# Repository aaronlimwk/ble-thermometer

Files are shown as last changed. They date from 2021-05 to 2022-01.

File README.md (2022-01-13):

# BLE Contactless Thermometer 🤒
A BLE contactless thermometer which can distinguish between colds and the flu!

## Front & Back View 🌡️
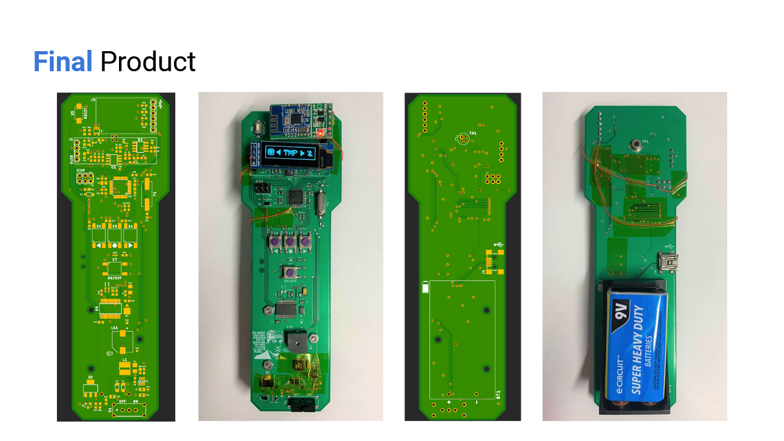
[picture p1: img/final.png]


## Features ⚙️
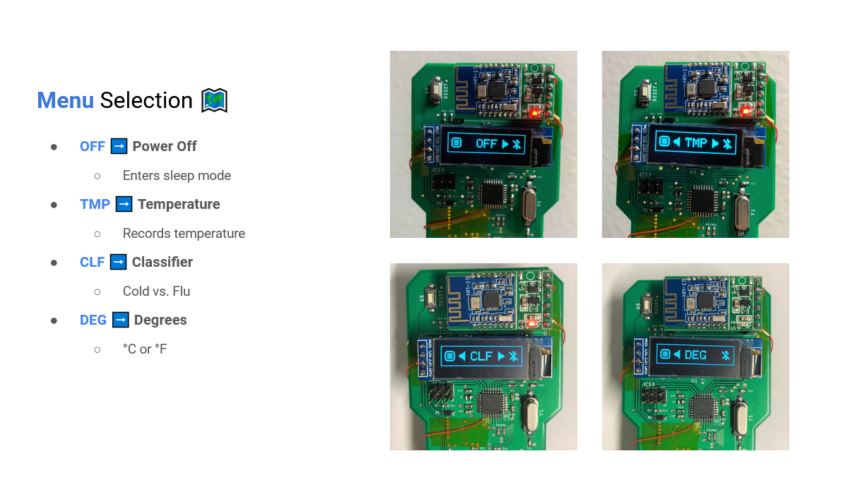
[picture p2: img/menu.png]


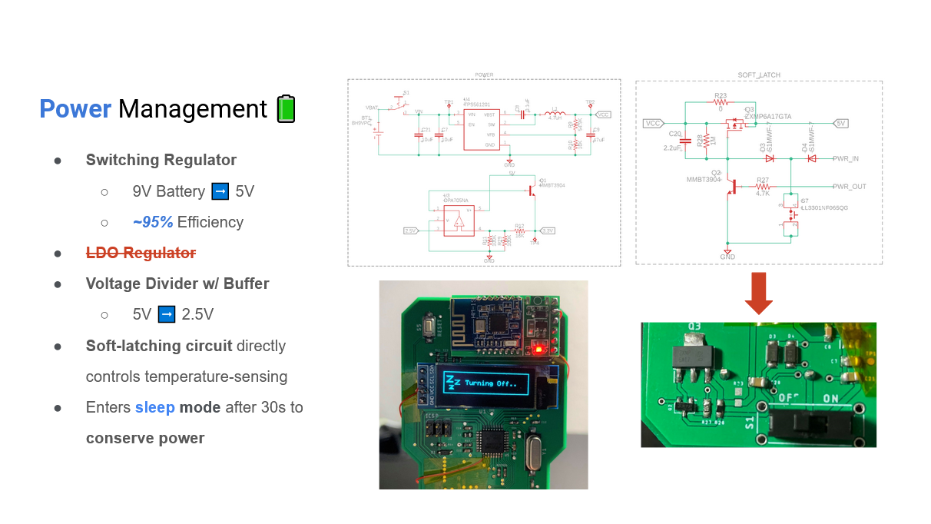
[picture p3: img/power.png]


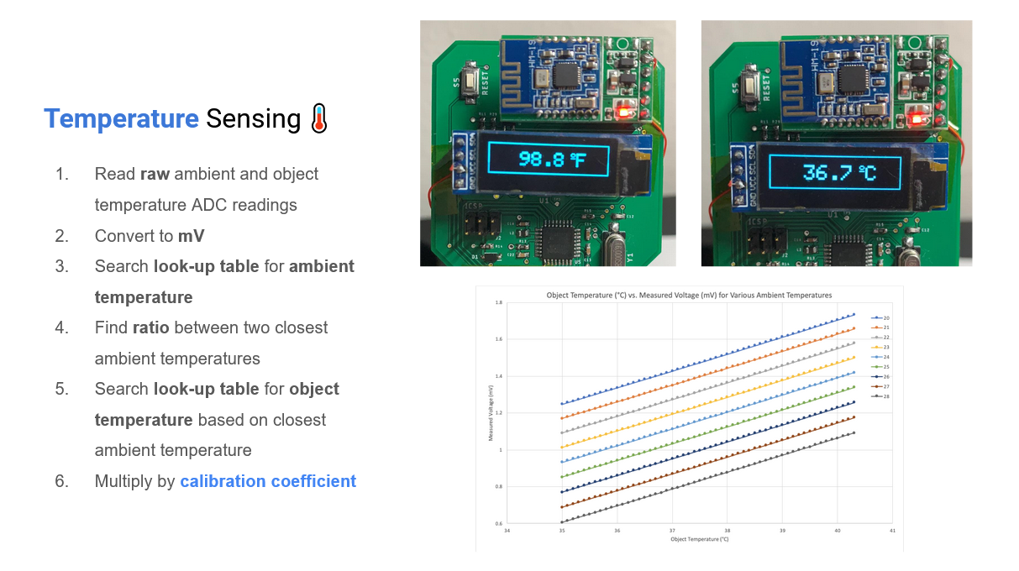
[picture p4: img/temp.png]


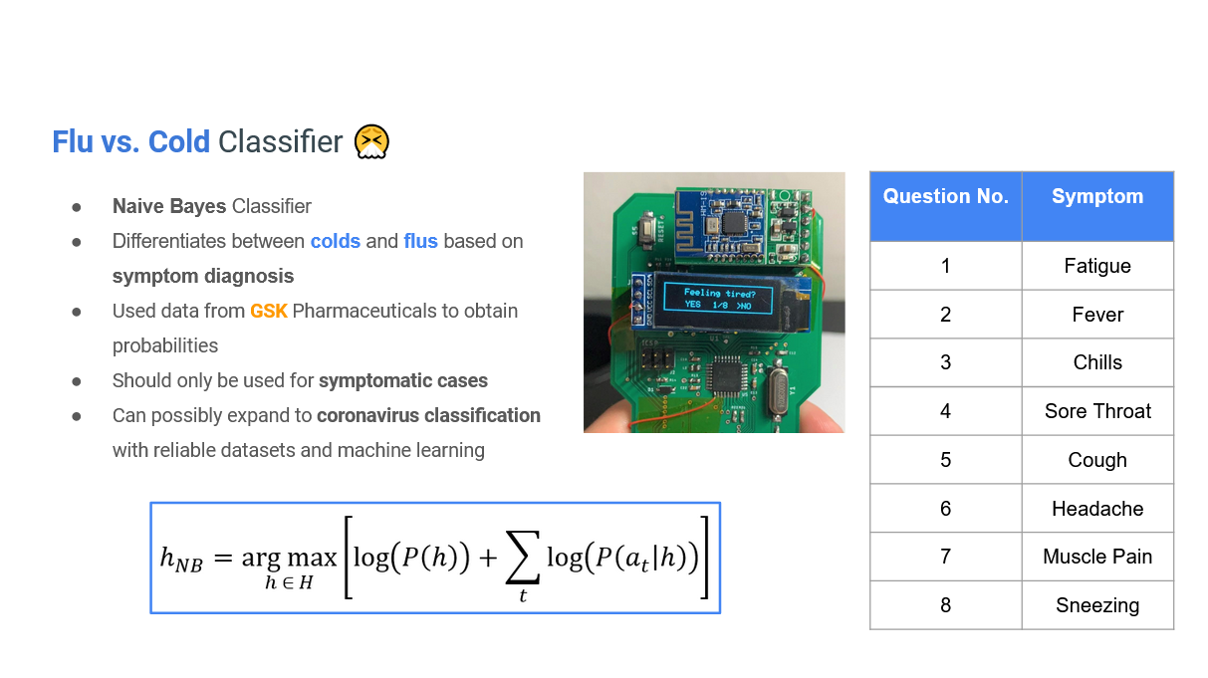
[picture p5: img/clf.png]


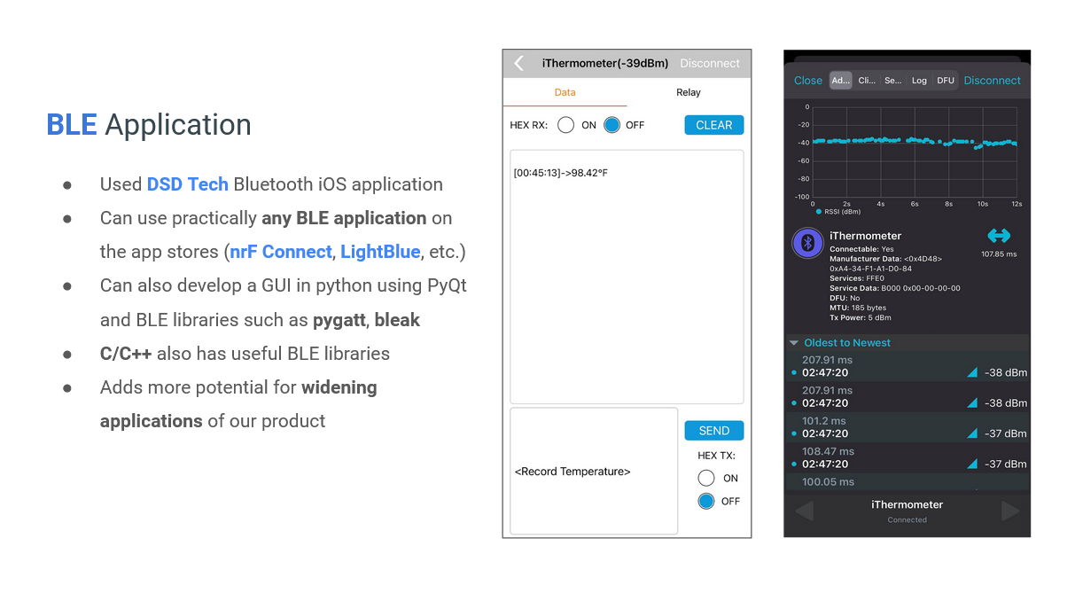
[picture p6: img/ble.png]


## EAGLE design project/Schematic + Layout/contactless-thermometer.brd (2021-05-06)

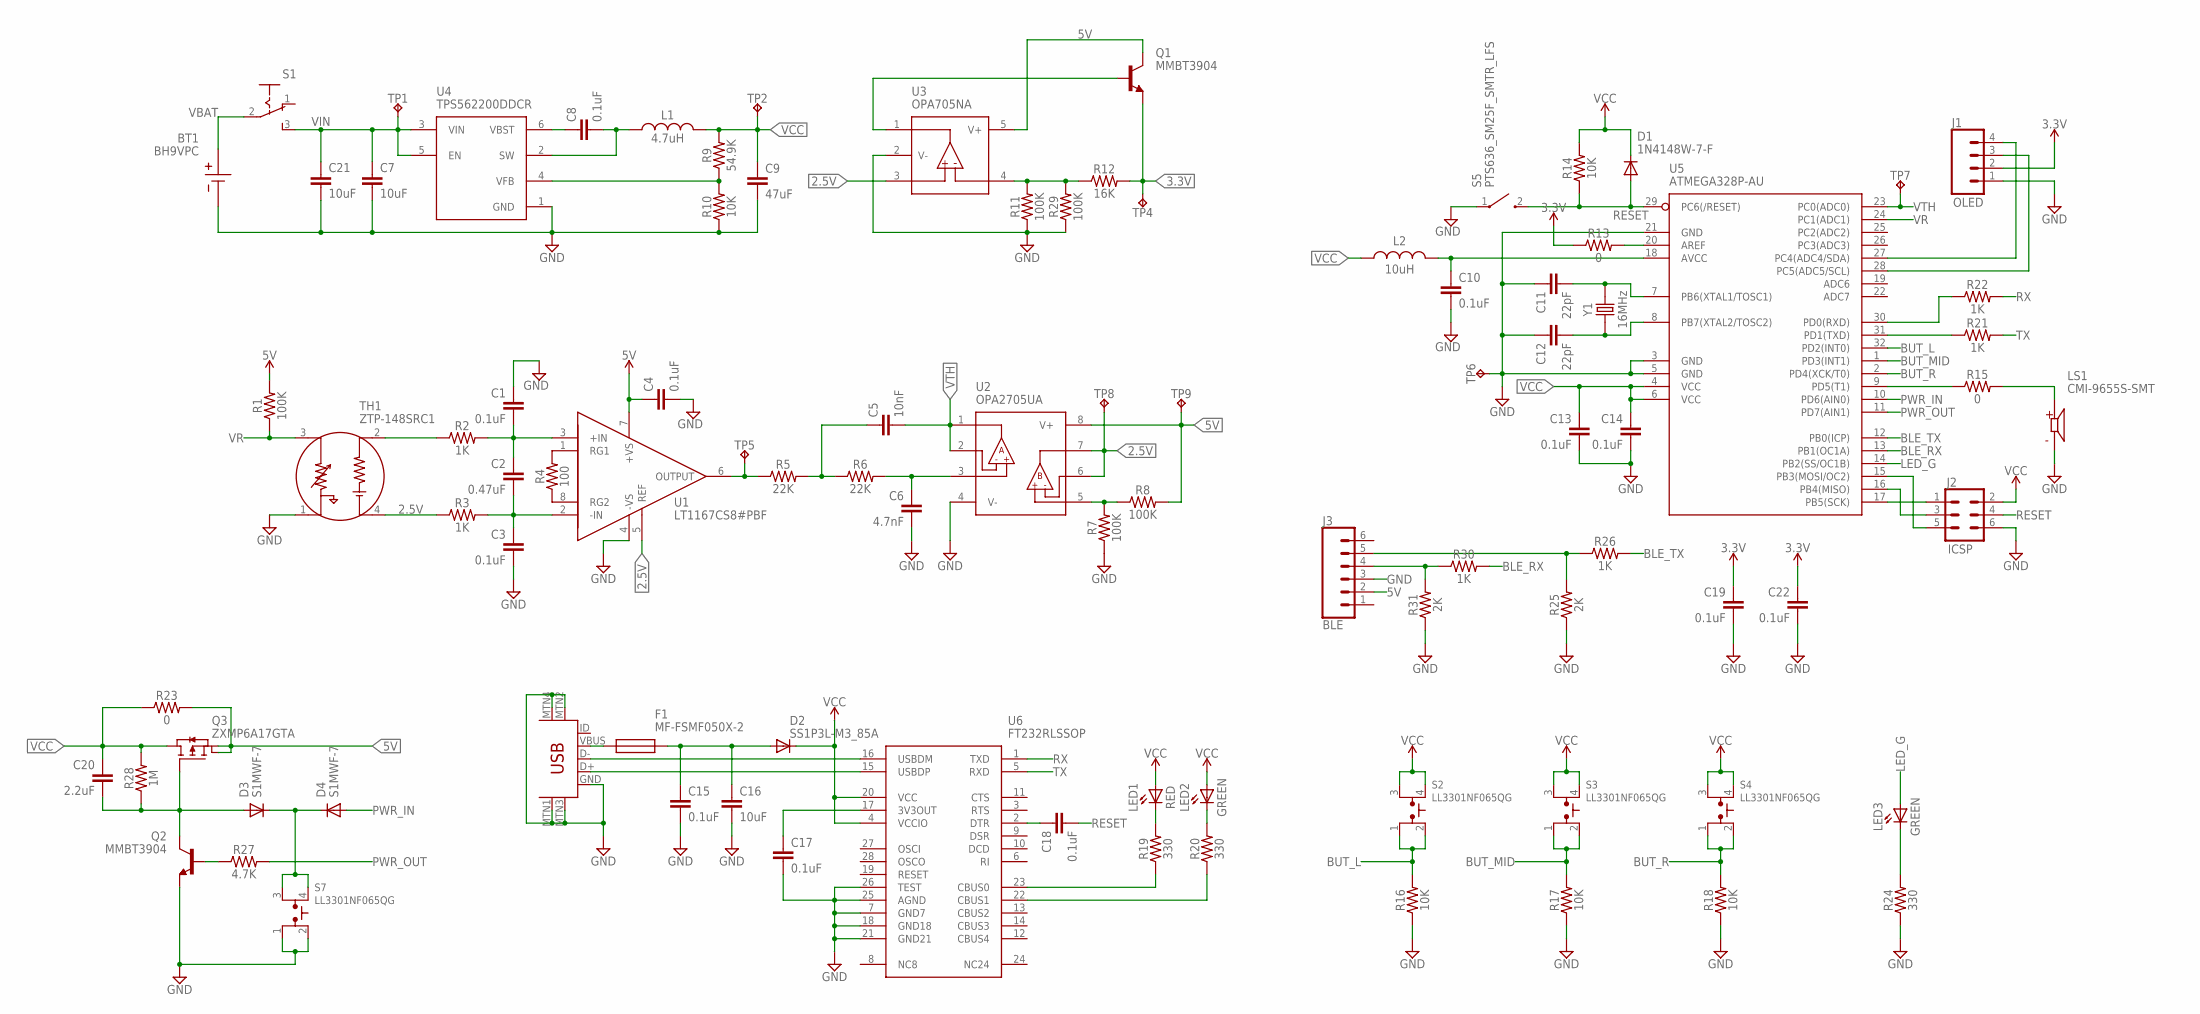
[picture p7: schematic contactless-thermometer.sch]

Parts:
BT1: BH9VPC; BAT_BH9VPC
C1, C3, C4, C8, C10, C13, C14, C15, C17, C18, C19, C22: 0.1uF; 0603
C2: 0.47uF; 0603
C5: 10nF; 0603
C6: 4.7nF; 0603
C7, C21: 10uF; CAPC2012X145N
C9: 47uF; 1206
C11, C12: 22pF; 0603
C16: 10uF; 1206
C20: 2.2uF; CAPC2012X145N
D1: 1N4148W-7-F; SOD3716X145N
D2: SS1P3L-M3_85A; SMP
D3, D4: S1MWF-7; SODFL3518X115N
F1: MF-FSMF050X-2; FUSC1608X100N
J1: OLED; 1X04
J2: ICSP; 2X3
J3: BLE; 1X06
J4: USB-MINIB-5PIN; USB-MINIB
L1: 4.7uH; VLCF5020T4R7N1R71
L2: 10uH; INDC2012X145N
LED1: RED; AA1608CGSK
LED2, LED3: GREEN; AA1608CGSK
LS1: CMI-9655S-SMT; CUI_CMI-9655S-SMT
Q1, Q2: MMBT3904; SOT23_NXP
Q3: ZXMP6A17GTA; SOT230P700X180-4N
R1, R7, R8, R11, R29: 100K; 0603
R2, R3, R21, R22, R26, R30: 1K; 0603
R4: 100; 0603
R5, R6: 22K; 0603
R9: 54.9K; 0603
R10, R14, R16, R17, R18: 10K; 0603
R12: 16K; 0603
R13, R15, R23: 0; 0603
R19, R20, R24: 330; 0603
R25, R31: 2K; 0603
R27: 4.7K; 0603
R28: 1M; 0603
S1: SK12F17G7; SW3_2F17G7_CNK
S2, S3, S4, S7: LL3301NF065QG
S5: PTS636_SM25F_SMTR_LFS; PTS636SM25FSMTRLFS
TH1: ZTP-148SRC1; XDCR_ZTP-148SRC1
TP1, TP2, TP4, TP5, TP6, TP7, TP8, TP9: TPTP10R; TP10R
U1: LT1167CS8#PBF; SOIC127P599X175-8N
U2: OPA2705UA; SOIC127P600X175-8N
U3: OPA705NA; SOT95P280X145-5N
U4: TPS562200DDCR; SOT95P280X110-6N
U5: ATMEGA328P-AU; TQFP32-08
U6: FT232RLSSOP; SOP65P780X200-28N
Y1: 16MHz; XTAL_ECS-240-20-5PX-TR

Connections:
2.5V: R3.1, TH1.4 (THERMOPILE_GND), TP8.TP, U1.5 (REF), U2.6 (-INB), U2.7 (OUTB), U3.3 (+IN)
3.3V: C19.1, C22.1, J1.2, Q1.2, R12.2, R13.1, TP4.TP
5V: C4.1, J3.2, Q1.3, Q3.2 (D1), Q3.4 (D2), R1.2, R8.2, R23.2, TP9.TP, U1.7 (+VS), U2.8 (V+), U3.5 (V+)
AVCC: C10.1, L2.2, U5.18 (AVCC)
BLE_RX: R30.2, U5.13 (PB1(OC1A))
BLE_TX: R26.2, U5.12 (PB0(ICP))
BUT_L: R16.2, S2.1, S2.2, U5.32 (PD2(INT0))
BUT_MID: R17.2, S3.1, S3.2, U5.1 (PD3(INT1))
BUT_R: R18.2, S4.1, S4.2, U5.2 (PD4(XCK/T0))
BUZZ: R15.1, U5.9 (PD5(T1))
DTR: C18.1, U6.2 (DTR)
GND: BT1.-, C1.1, C3.2, C4.2, C6.2, C7.1, C9.2, C10.2, C11.1, C12.1, C13.2, C14.2, C15.2, C16.2, C17.2, C19.2, C21.1, C22.2, J1.1, J2.6, J3.3, J4.GND, J4.MTN1 (MTN2), J4.MTN2 (MTN3), J4.MTN3 (MTN1), J4.MTN4, LS1.N, Q2.2, R7.1, R10.1, R11.1, R16.1, R17.1, R18.1, R24.1, R25.1, R29.1, R31.1, S5.1 (COM), S7.1, S7.2, TH1.1 (THERMISTOR_GND), TP6.TP, U1.4 (-VS), U2.4 (V-), U3.2 (V-), U4.1 (GND), U5.3 (GND), U5.5 (GND), U5.21 (GND), U6.7 (GND7), U6.18 (GND18), U6.21 (GND21), U6.25 (AGND), U6.26 (TEST)
LED_G: LED3.2 (A), U5.14 (PB2(SS/OC1B))
unnamed: C1.2, C2.1, R2.2, U1.3 (+IN)
unnamed: R4.2, U1.1 (RG1)
unnamed: R2.1, TH1.2 (THERMOPILE)
unnamed: C2.2, C3.1, R3.2, U1.2 (-IN)
unnamed: R7.2, R8.1, U2.5 (+INB)
unnamed: R4.1, U1.8 (RG2)
unnamed: R5.1, TP5.TP, U1.6 (OUTPUT)
unnamed: LS1.P, R15.2
unnamed: C5.1, R5.2, R6.1
unnamed: C6.1, R6.2, U2.3 (+INA)
unnamed: R13.2, U5.20 (AREF)
unnamed: J4.D-, U6.16 (USBDM)
unnamed: J4.D+, U6.15 (USBDP)
unnamed: J2.1, U5.17 (PB5(SCK))
unnamed: C8.1, U4.6 (VBST)
unnamed: C11.2, U5.7 (PB6(XTAL1/TOSC1)), Y1.2
unnamed: C12.2, U5.8 (PB7(XTAL2/TOSC2)), Y1.1
unnamed: J2.3, U5.16 (PB4(MISO))
unnamed: C8.2, L1.1, U4.2 (SW)
unnamed: J2.5, U5.15 (PB3(MOSI/OC2))
unnamed: R9.1, R10.2, U4.4 (VFB)
unnamed: R11.2, R12.1, R29.2, U3.4 (-IN)
unnamed: R19.1, U6.23 (CBUS0)
unnamed: J1.4, U5.27 (PC4(ADC4/SDA))
unnamed: LED1.1 (K), R19.2
unnamed: R20.1, U6.22 (CBUS1)
unnamed: J1.3, U5.28 (PC5(ADC5/SCL))
unnamed: LED2.1 (K), R20.2
unnamed: C17.1, U6.17 (3V3OUT)
unnamed: F1.1, J4.VBUS
unnamed: Q1.1, U3.1 (OUT)
unnamed: C15.1, C16.1, D2.1 (A), F1.2
unnamed: R21.1, U5.31 (PD1(TXD))
unnamed: R22.1, U5.30 (PD0(RXD))
unnamed: J3.4, R30.1, R31.2
unnamed: Q2.1, R27.1
unnamed: LED3.1 (K), R24.2
unnamed: J3.5, R25.2, R26.1
unnamed: C20.1, D3.2 (A), Q2.3, Q3.1 (G), R28.1
unnamed: D3.1 (K), D4.1 (K), S7.3, S7.4
PWR_IN: D4.2 (A), U5.10 (PD6(AIN0))
PWR_OUT: R27.2, U5.11 (PD7(AIN1))
RESET: C18.2, D1.2 (A), J2.4, R14.1, S5.2 (NO), U5.29 (PC6(/RESET))
RX: R22.2, U6.1 (TXD)
TX: R21.2, U6.5 (RXD)
VBAT: BT1.+, S1.2
VCC: C9.1, C13.1, C14.1, C20.2, D1.1 (K), D2.2 (K), J2.2, L1.2, L2.1, LED1.2 (A), LED2.2 (A), Q3.3 (S), R9.2, R14.2, R23.1, R28.2, S2.3, S2.4, S3.3, S3.4, S4.3, S4.4, TP2.TP, U5.4 (VCC), U5.6 (VCC), U6.4 (VCCIO), U6.20 (VCC)
VIN: C7.2, C21.2, S1.3, TP1.TP, U4.3 (VIN), U4.5 (EN)
VR: R1.1, TH1.3 (THERMISTOR), U5.24 (PC1(ADC1))
VTH: C5.2, TP7.TP, U2.1 (OUTA), U2.2 (-INA), U5.23 (PC0(ADC0))

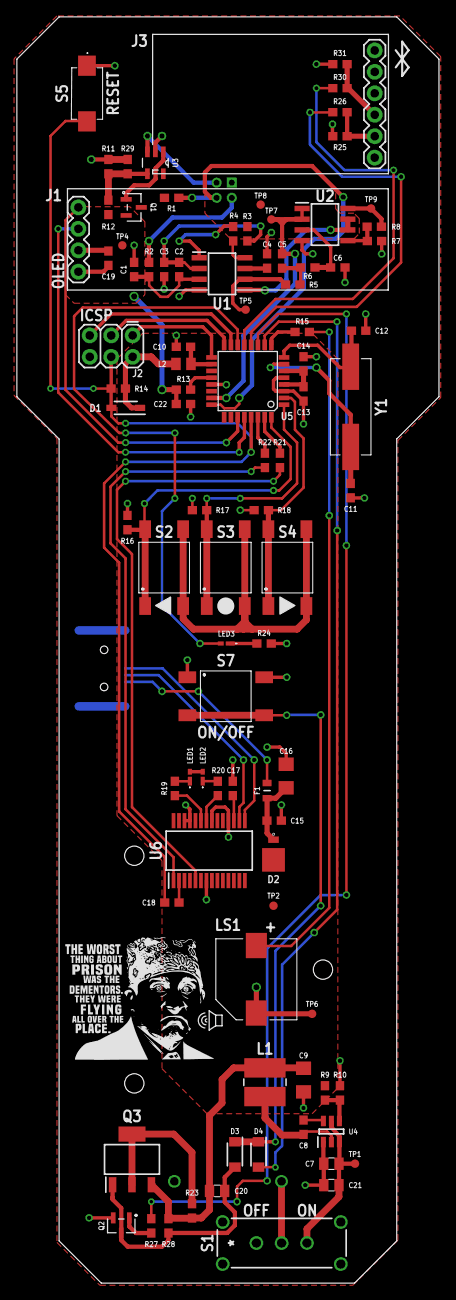
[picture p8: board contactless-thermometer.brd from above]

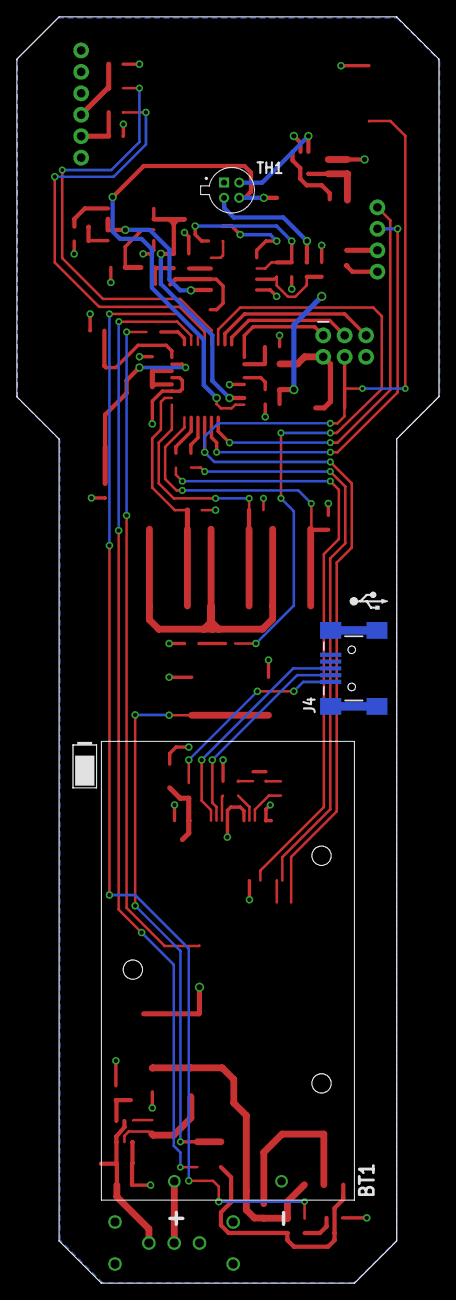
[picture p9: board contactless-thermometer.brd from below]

Board: 2 copper layers, 50.0 x 150.0 mm, 94 parts (3 on the bottom side), 63 nets.

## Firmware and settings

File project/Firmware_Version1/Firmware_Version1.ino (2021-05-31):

#include <SoftwareSerial.h>
#include <OneButton.h>
#include <Wire.h>
#include <Adafruit_SSD1306.h>
#include <avr/pgmspace.h>
#include <RunningMedian.h>

// Baud Rate
#define baud 9600

// Pin Definitions
#define BUT_L             2
#define BUT_MID           3
#define BUT_R             4
#define BUZZ              5
#define PWR_IN            6
#define PWR_OUT           7
#define LED               10
#define VTH               14
#define VR                15
#define BLE_STATE         16

// Bluetooth Message Handler + Setup
char message[20];
bool message_incoming = false;
SoftwareSerial mySerial(9, 8); // RX, TX
int ble_conn_count = 0;
bool ble_connected = false;

// Sleep Sequence Frames
#define SLEEP_FRAMES      4

// OLED Definitions
#define SCREEN_WIDTH      128 // OLED display width, in pixels
#define SCREEN_HEIGHT     32 // OLED display height, in pixels
#define OLED_RESET        -1 // Reset pin # (or -1 if sharing Arduino reset pin)
#define SCREEN_ADDRESS    0x3C ///< See datasheet for Address; 0x3D for 128x64, 0x3C for 128x32
Adafruit_SSD1306 display(SCREEN_WIDTH, SCREEN_HEIGHT, &Wire, OLED_RESET);

// 'Menu Bar Icon', 20x20px
const unsigned char menu_bmp [] PROGMEM = {
  0x00, 0x00, 0x00, 0x00, 0x00, 0x00, 0x07, 0xfe, 0x00, 0x1f, 0xff, 0x80, 0x18, 0x01, 0x80, 0x30,
  0x00, 0xc0, 0x33, 0xfc, 0xc0, 0x33, 0xfc, 0xc0, 0x30, 0x00, 0xc0, 0x33, 0xfc, 0xc0, 0x33, 0xfc,
  0xc0, 0x30, 0x00, 0xc0, 0x33, 0xfc, 0xc0, 0x33, 0xfc, 0xc0, 0x30, 0x00, 0xc0, 0x18, 0x01, 0x80,
  0x1f, 0xff, 0x80, 0x07, 0xfe, 0x00, 0x00, 0x00, 0x00, 0x00, 0x00, 0x00
};

// 'Bluetooth Disabled Icon', 20x20px
const unsigned char ble_off_bmp [] PROGMEM = {
  0x00, 0x00, 0x00, 0x00, 0x00, 0x00, 0x00, 0x60, 0x00, 0x08, 0x70, 0x00, 0x1c, 0x78, 0x00, 0x0e,
  0x7c, 0x00, 0x07, 0x2e, 0x00, 0x03, 0x9c, 0x00, 0x01, 0xc8, 0x00, 0x00, 0xe0, 0x00, 0x00, 0xf0,
  0x00, 0x01, 0xf8, 0x00, 0x03, 0xfc, 0x00, 0x07, 0x6e, 0x00, 0x0e, 0x6f, 0x00, 0x04, 0x7b, 0x80,
  0x00, 0x71, 0x00, 0x00, 0x60, 0x00, 0x00, 0x00, 0x00, 0x00, 0x00, 0x00
};

// 'Bluetooth Enabled Icon', 20x20px
const unsigned char ble_on_bmp [] PROGMEM = {
  0x00, 0x00, 0x00, 0x00, 0x00, 0x00, 0x00, 0x60, 0x00, 0x00, 0x70, 0x00, 0x04, 0x78, 0x00, 0x0e,
  0x7c, 0x00, 0x07, 0x6e, 0x00, 0x03, 0xfc, 0x00, 0x01, 0xf8, 0x00, 0x00, 0xf0, 0x00, 0x00, 0xf0,
  0x00, 0x01, 0xf8, 0x00, 0x03, 0xfc, 0x00, 0x07, 0x6e, 0x00, 0x0e, 0x7c, 0x00, 0x04, 0x78, 0x00,
  0x00, 0x70, 0x00, 0x00, 0x60, 0x00, 0x00, 0x00, 0x00, 0x00, 0x00, 0x00
};

// 'Sleeping Mode Icon', 20x20px
const unsigned char sleep_bmp [] PROGMEM = {
  0xff, 0xc0, 0x00, 0x7f, 0xc0, 0x00, 0x01, 0x80, 0x00, 0x03, 0x00, 0x00, 0x06, 0x00, 0x00, 0x0c,
  0x00, 0x00, 0x18, 0x0f, 0xf0, 0x30, 0x00, 0x60, 0x7f, 0xc0, 0xc0, 0xff, 0xc1, 0x80, 0x00, 0x03,
  0x00, 0x00, 0x06, 0x00, 0x00, 0x0f, 0xf0, 0x00, 0x00, 0x00, 0x0f, 0xe0, 0x00, 0x00, 0xc0, 0x00,
  0x01, 0x80, 0x00, 0x03, 0x00, 0x00, 0x07, 0xc0, 0x00, 0x0f, 0xe0, 0x00
};

const char string_off[] PROGMEM = "OFF";
const char string_tmp[] PROGMEM = "TMP";
const char string_clf[] PROGMEM = "CLF";
const char string_deg[] PROGMEM = "DEG";

const char *const string_table[] PROGMEM = {string_off, string_tmp, string_clf, string_deg};

char buffer[20];

// Classifier Declarations
#define MAX_QUESTION      8

const char question_1[] PROGMEM = "Feeling tired?"; // (24, 6)
const char question_2[] PROGMEM = "Fever?";         // (50, 6)
const char question_3[] PROGMEM = "Chills?";        // (46, 6)
const char question_4[] PROGMEM = "Sore throat?";   // (28, 6)
const char question_5[] PROGMEM = "Coughing?";      // (40, 6)
const char question_6[] PROGMEM = "Headache?";      // (40, 6)
const char question_7[] PROGMEM = "Muscle pain?";   // (28, 6)
const char question_8[] PROGMEM = "Sneezing?";      // (40, 6)

int question_num = 0;

const char *const questions[] PROGMEM = {question_1, question_2, question_3, question_4, question_5, question_6, question_7, question_8};
const int position_x[8] = {24, 50, 47, 29, 40, 40, 29, 40};

#define FLU               0.001

const float flu_table[] PROGMEM = {0.8, 0.9, 0.9, 0.55, 0.9, 0.85, 0.675, 0.25};
float prob_flu = log(FLU);

#define COLD              0.999

const float cold_table[] PROGMEM = {0.225, 0.005, 0.1, 0.5, 0.4, 0.25, 0.1, 0.9};
float prob_cold = log(COLD);

// State Definitions
#define SLEEP_STATE       -1
#define MIN_STATE         0
#define DEFAULT_STATE     1
#define CLF_STATE         2
#define MAX_STATE         3

#define TEMP_REC_STATE    10

#define CLF_NO_STATE      30
#define CLF_YES_STATE     31

#define CELSIUS_STATE     40
#define FAHRENHEIT_STATE  41

#define MAX_TIME          25000
#define SLEEP_TIME        30000

#define SAMPLE_SIZE       40
#define ADC_RES           1024
#define V_REF             5
#define OFFSET            2.5
#define GAIN              1977
#define MV                1000
#define CAL_CONST         0.725
#define NUM_AMBIENT       11
#define MAX_TEMP_SIZE     54

RunningMedian temp_samples = RunningMedian(SAMPLE_SIZE);

double temp_c = 0;
double temp_f = 0;

bool deg_celsius = true;

int state = DEFAULT_STATE;
unsigned long last_millis = 0;
unsigned long last_interrupt_millis = 0;

// Button Setup
OneButton but_left = OneButton(BUT_L, false, false);
OneButton but_middle = OneButton(BUT_MID, false, false);
OneButton but_right = OneButton(BUT_R, false, false);

// Power Button
bool power_on = false;
OneButton pwr_in = OneButton(PWR_IN, true, true);

// Temperature Chart
const float temp_chart[11][54] PROGMEM = {
  // 20 degrees Celsius
  { 1.247, 1.256, 1.265, 1.274, 1.283, 1.292, 1.301, 1.310, 1.319, 1.328, 1.337, 1.346, 1.355, 1.364, 1.373, 1.382, 1.391, 1.400, 1.409, 1.418, 1.427, 1.437, 1.446, 1.455, 1.464, 1.473, 1.482,
    1.491, 1.501, 1.510, 1.519, 1.528, 1.537, 1.547, 1.556, 1.565, 1.574, 1.584, 1.593, 1.602, 1.612, 1.621, 1.630, 1.639, 1.649, 1.658, 1.668, 1.677, 1.686, 1.696, 1.705, 1.714, 1.724, 1.733
  },
  // 21 degrees Celsius
  { 1.169, 1.178, 1.187, 1.196, 1.205, 1.214, 1.223, 1.232, 1.241, 1.250, 1.259, 1.268, 1.277, 1.286, 1.295, 1.305, 1.314, 1.323, 1.332, 1.341, 1.350, 1.359, 1.368, 1.377, 1.387, 1.396, 1.405,
    1.414, 1.423, 1.432, 1.442, 1.451, 1.460, 1.469, 1.479, 1.488, 1.497, 1.506, 1.516, 1.525, 1.534, 1.543, 1.553, 1.562, 1.571, 1.581, 1.590, 1.599, 1.609, 1.618, 1.628, 1.637, 1.646, 1.656
  },
  // 22 degrees Celsius
  { 1.091, 1.100, 1.109, 1.118, 1.127, 1.136, 1.145, 1.154, 1.163, 1.172, 1.181, 1.190, 1.199, 1.208, 1.217, 1.226, 1.235, 1.245, 1.254, 1.263, 1.272, 1.281, 1.290, 1.299, 1.308, 1.318, 1.327,
    1.336, 1.345, 1.354, 1.363, 1.373, 1.382, 1.391, 1.400, 1.410, 1.419, 1.428, 1.437, 1.447, 1.456, 1.465, 1.475, 1.484, 1.493, 1.503, 1.512, 1.521, 1.531, 1.540, 1.549, 1.559, 1.568, 1.578
  },
  // 23 degrees Celsius
  { 1.012, 1.021, 1.030, 1.039, 1.048, 1.057, 1.066, 1.075, 1.084, 1.093, 1.102, 1.111, 1.120, 1.129, 1.138, 1.147, 1.156, 1.166, 1.175, 1.184, 1.193, 1.202, 1.211, 1.220, 1.229, 1.239, 1.248,
    1.257, 1.266, 1.275, 1.284, 1.294, 1.303, 1.312, 1.321, 1.331, 1.340, 1.349, 1.358, 1.368, 1.377, 1.386, 1.396, 1.405, 1.414, 1.424, 1.433, 1.442, 1.452, 1.461, 1.470, 1.480, 1.489, 1.499
  },
  // 24 degrees Celsius
  { 0.932, 0.941, 0.950, 0.959, 0.968, 0.977, 0.986, 0.995, 1.004, 1.013, 1.022, 1.031, 1.040, 1.049, 1.058, 1.068, 1.077, 1.086, 1.095, 1.104, 1.113, 1.122, 1.131, 1.140, 1.150, 1.159, 1.168,
    1.177, 1.186, 1.195, 1.205, 1.214, 1.223, 1.232, 1.242, 1.251, 1.260, 1.269, 1.279, 1.288, 1.297, 1.306, 1.316, 1.325, 1.334, 1.344, 1.353, 1.362, 1.372, 1.381, 1.391, 1.400, 1.409, 1.419
  },
  // 25 degrees Celsius
  { 0.852, 0.861, 0.870, 0.879, 0.888, 0.897, 0.906, 0.915, 0.924, 0.933, 0.942, 0.951, 0.960, 0.969, 0.978, 0.987, 0.996, 1.005, 1.014, 1.023, 1.032, 1.042, 1.051, 1.060, 1.069, 1.078, 1.087,
    1.096, 1.106, 1.115, 1.124, 1.133, 1.142, 1.152, 1.161, 1.170, 1.179, 1.189, 1.198, 1.207, 1.217, 1.226, 1.235, 1.245, 1.254, 1.263, 1.273, 1.282, 1.291, 1.301, 1.310, 1.319, 1.329, 1.338
  },
  // 26 degrees Celsius
  { 0.770, 0.779, 0.788, 0.797, 0.806, 0.815, 0.824, 0.833, 0.842, 0.851, 0.860, 0.869, 0.878, 0.887, 0.896, 0.906, 0.915, 0.924, 0.933, 0.942, 0.951, 0.960, 0.969, 0.978, 0.988, 0.997, 1.006,
    1.015, 1.024, 1.033, 1.043, 1.052, 1.061, 1.070, 1.080, 1.089, 1.098, 1.107, 1.117, 1.126, 1.135, 1.144, 1.154, 1.163, 1.172, 1.182, 1.191, 1.200, 1.210, 1.219, 1.229, 1.238, 1.247, 1.257
  },
  // 27 degrees Celsius
  { 0.688, 0.697, 0.706, 0.715, 0.724, 0.733, 0.742, 0.751, 0.760, 0.769, 0.778, 0.787, 0.796, 0.805, 0.814, 0.823, 0.832, 0.841, 0.851, 0.860, 0.869, 0.878, 0.887, 0.896, 0.905, 0.914, 0.924,
    0.933, 0.942, 0.951, 0.960, 0.970, 0.979, 0.988, 0.997, 1.007, 1.016, 1.025, 1.034, 1.044, 1.053, 1.062, 1.072, 1.081, 1.090, 1.100, 1.109, 1.118, 1.128, 1.137, 1.147, 1.156, 1.165, 1.175
  },
  // 28 degrees Celsius
  { 0.605, 0.614, 0.623, 0.632, 0.641, 0.650, 0.659, 0.668, 0.677, 0.686, 0.695, 0.704, 0.713, 0.722, 0.731, 0.740, 0.749, 0.758, 0.767, 0.777, 0.786, 0.795, 0.804, 0.813, 0.822, 0.831, 0.841,
    0.850, 0.859, 0.868, 0.877, 0.887, 0.896, 0.905, 0.914, 0.923, 0.933, 0.942, 0.951, 0.961, 0.970, 0.979, 0.988, 0.998, 1.007, 1.016, 1.026, 1.035, 1.045, 1.054, 1.063, 1.073, 1.082, 1.091
  },
  // 29 degrees Celsius
  { 0.521, 0.530, 0.539, 0.548, 0.557, 0.566, 0.575, 0.584, 0.593, 0.602, 0.611, 0.620, 0.629, 0.638, 0.647, 0.656, 0.665, 0.674, 0.684, 0.693, 0.702, 0.711, 0.720, 0.729, 0.738, 0.748, 0.757,
    0.766, 0.775, 0.784, 0.793, 0.803, 0.812, 0.821, 0.830, 0.840, 0.849, 0.858, 0.867, 0.877, 0.886, 0.895, 0.905, 0.914, 0.923, 0.933, 0.942, 0.951, 0.961, 0.970, 0.979, 0.989, 0.998, 1.008
  },
  // 30 degrees Celsius
  { 0.436, 0.445, 0.454, 0.463, 0.472, 0.481, 0.490, 0.499, 0.508, 0.517, 0.526, 0.535, 0.544, 0.553, 0.563, 0.572, 0.581, 0.590, 0.599, 0.608, 0.617, 0.626, 0.635, 0.644, 0.654, 0.663, 0.672,
    0.681, 0.690, 0.699, 0.709, 0.718, 0.727, 0.736, 0.746, 0.755, 0.764, 0.773, 0.783, 0.792, 0.801, 0.811, 0.820, 0.829, 0.838, 0.848, 0.857, 0.867, 0.876, 0.885, 0.895, 0.904, 0.913, 0.923
  }
};

// Ambient Temperature Chart
const float ambient_chart[11] PROGMEM = {2.78, 2.72, 2.67, 2.61, 2.55, 2.5, 2.45, 2.39, 2.34, 2.28, 2.23};

void setup() {
  // Pin Setup
  pinMode(BLE_STATE, INPUT);
  pinMode(VTH, INPUT);
  pinMode(PWR_OUT, OUTPUT);
  pinMode(LED, OUTPUT);
  pinMode(BUZZ, OUTPUT);
  //Turn off LED
  digitalWrite(LED, LOW);

  // Begin Serial Communication for HM-11 and Board
  mySerial.begin(baud);

  // Button Click - Function Link
  but_left.attachClick(leftClick);
  but_left.attachLongPressStart(holdLeft);

  but_right.attachClick(rightClick);

  but_middle.attachClick(middleClick);
  but_middle.attachLongPressStart(holdClick);

  pwr_in.attachClick(powerON);
  pwr_in.attachLongPressStart(holdRecord);

  // OLED Setup
  // SSD1306_SWITCHCAPVCC => Generate display voltage from 3.3V internally
  if (!display.begin(SSD1306_SWITCHCAPVCC, SCREEN_ADDRESS)) {
    // Serial.println(F("SSD1306 allocation failed"));
    for (;;); // Don't proceed, loop forever!
  }

  // Show initial display buffer contents on the screen.
  // The library initializes this with an Adafruit splash screen.
  display.display();
  delay(1750); // Pause for 2 seconds

  // Clear the buffer
  display.clearDisplay();

  // Default Font
  display.setTextSize(2);
  display.setTextColor(SSD1306_WHITE);
  display.cp437(true);

  // BLE Setup
  at("AT+NAMEiThermometer");
  at("AT+ROLE0"); // Set peripheral mode
  at("AT+IMME0"); // Work immediately
  at("AT+RESET"); // Actually more a restart than a reset => Needed after ROLE
  delay(1000);
}

void loop() {
  but_left.tick();
  but_right.tick();
  but_middle.tick();
  pwr_in.tick();

  display.clearDisplay();
  display.setTextSize(2);

  if (ble_connected == false) {
    if (digitalRead(BLE_STATE) == 1) {
      if (ble_conn_count == 20) {
        ble_connected = true;
        BLESequence();
        ble_conn_count = 0;
      } else {
        ble_conn_count++;
      }
    } else {
      ble_conn_count = 0;
    }
  }

  if (ble_connected == true) {
    if (digitalRead(BLE_STATE) == 0) {
      ble_connected = false;
      BLESequence();
    }
  }

  if (state != SLEEP_STATE) {
    if (millis() >= last_millis + SLEEP_TIME) {
      bussIT(100);
      state = SLEEP_STATE;
    } else if (millis() >= last_millis + MAX_TIME) {
      state = DEFAULT_STATE;
      reset();
    }
  }

  if (state == CLF_NO_STATE || state == CLF_YES_STATE) {
    display.drawRect(0, 0, display.width(), display.height(), SSD1306_WHITE);
    display.setTextSize(1);

    if (state == CLF_NO_STATE) {
      display.setCursor(25, 20);
      display.print("YES");
      display.setCursor(85, 20);
      display.print(">NO");
    } else {
      display.setCursor(19, 20);
      display.print(">YES");
      display.setCursor(91, 20);
      display.print("NO");
    }

    if (question_num < MAX_QUESTION) {
      display.setCursor(position_x[question_num], 6);
      strcpy_P(buffer, (char *)pgm_read_word(&(questions[question_num])));
      display.print(buffer);

      display.setCursor(57, 20);
      display.print(question_num + 1);
      display.print("/8");
    }

  } else if (state == CELSIUS_STATE || state == FAHRENHEIT_STATE) {
    display.drawRect(0, 0, display.width(), display.height(), SSD1306_WHITE);
    display.setCursor(25, 9);
    display.print("Unit:");
    display.setTextSize(1);
    display.write(167);
    display.setTextSize(2);

    if (state == CELSIUS_STATE) {
      display.print("C");
      display.setCursor(108, 9);
      display.write(16);
    } else {
      display.print("F");
      display.setCursor(8, 9);
      display.write(17);
    }
  } else if (state == TEMP_REC_STATE) {
    display.drawRect(0, 0, display.width(), display.height(), SSD1306_WHITE);
    if (temp_c >= 0) {
      display.setTextSize(2);
      if (!deg_celsius) {
        if (temp_f >= 100) {
          display.setCursor(21, 9);
        } else {
          display.setCursor(33, 9);
          if (temp_f == 0) {
            display.print("0");
          }
        }
        display.print(temp_f, 1);
        display.setTextSize(1);
        display.print(" ");
        display.write(167);
        display.setTextSize(2);
        display.print("F");
      } else {
        display.setCursor(33, 9);
        if (temp_c == 0) {
          display.print("0");
        }
        display.print(temp_c, 1);
        display.setTextSize(1);
        display.print(" ");
        display.write(167);
        display.setTextSize(2);
        display.print("C");
      }
    } else {
      temp_c = 0;
      temp_f = 0;
      display.setTextSize(1);
      display.setCursor(17, 8);
      display.print("Invalid reading.");
      display.setCursor(15, 18);
      display.print("Please try again!");
      refresh(2000);
    }
  } else if (state != SLEEP_STATE) {
    drawIcon();
    display.drawRect(0, 0, display.width(), display.height(), SSD1306_WHITE);
    if (state == MIN_STATE) {
      display.setCursor(90, 9);
      display.write(16);
    } else if (state == MAX_STATE) {
      display.setCursor(28, 9);
      display.write(17);
    } else {
      display.setCursor(28, 9);
      display.write(17);
      display.setCursor(90, 9);
      display.write(16);
    }
    display.setCursor(47, 9);
    strcpy_P(buffer, (char *)pgm_read_word(&(string_table[state])));
    display.print(buffer);
  }

  if (mySerial.available()) {
    char a = char(mySerial.read());
    if (!message_incoming) {
      if (a == '<') {
        message_incoming = true;
      }
    } else {
      if (a == '>') {
        message_incoming = false;
        if (strcmp("Record Temperature", message) == 0) {
          if (power_on == false) {
            display.clearDisplay();
            display.setTextSize(1);
            display.drawRect(0, 0, display.width(), display.height(), SSD1306_WHITE);
            display.setCursor(15,8);
            display.print("Reading remotely!");
            display.setCursor(30,18);
            display.print("Please wait");
            display.display();
            printPeriod();
            powerON();
            delay(500);
            printPeriod();
            recordData();
            printPeriod();
            delay(200);

            if (temp_c >= 0) {
              if (deg_celsius) {
                if (temp_c >= 0) {
                  mySerial.print(temp_c);
                  mySerial.print("°C");
                }
                // ADD "ºC"
              } else {
                mySerial.print(temp_f);
                mySerial.print("°F");
              }
            } else {
              mySerial.print("Invalid Temperature");
            }
          } else {
            mySerial.print("Try Again");
          }
          powerOFF();
        }
        memset(&message[0], 0, sizeof(message));
      } else {
        strncat(message, &a, 1);
      }
    }
  }
  refresh(10);
}

void printPeriod() {
  display.print(".");
  display.display();
}

void at(char* cmd) {
  mySerial.write(cmd);
  // Serial.print(cmd);
  while (!mySerial.find("OK"));
  // Serial.print(".");
}

void leftClick() {
  if (state == FAHRENHEIT_STATE) {
    last_millis = millis();
    state = CELSIUS_STATE;
    reset();
  } else if (state > MIN_STATE && state <= MAX_STATE) {
    last_millis = millis();
    state--;
  } else if (state == CLF_NO_STATE) {
    last_millis = millis();
    state = CLF_YES_STATE;
  }
}

void rightClick() {
  if (state == CELSIUS_STATE) {
    last_millis = millis();
    state = FAHRENHEIT_STATE;
  } else if (state >= MIN_STATE && state < MAX_STATE) {
    last_millis = millis();
    state++;
  } else if (state == CLF_YES_STATE) {
    last_millis = millis();
    state = CLF_NO_STATE;
  }
}

void middleClick() {
  last_millis = millis();
  if (state == SLEEP_STATE) {
    state = DEFAULT_STATE;
  } else if (state == CLF_STATE) {
    state = CLF_NO_STATE;
  } else if (state == MAX_STATE) {
    state = CELSIUS_STATE;
  } else if (state == CLF_YES_STATE || state == CLF_NO_STATE) {
    if (state == CLF_YES_STATE) {
      prob_flu += log(pgm_read_float_near(flu_table + question_num));
      prob_cold += log(pgm_read_float_near(cold_table + question_num));
    } else {
      prob_flu += log(1 - pgm_read_float_near(flu_table + question_num));
      prob_cold += log(1 - pgm_read_float_near(cold_table + question_num));
    }
    if (question_num + 1 <= MAX_QUESTION) {
      question_num++;
      state = CLF_NO_STATE;
      if (question_num == MAX_QUESTION) {
        probSequence();
        state = DEFAULT_STATE;
        reset();
      }
    }
  } else if (state == DEFAULT_STATE) {
    if (power_on == false) {
      powerON();
    }
    state = TEMP_REC_STATE;
  }
}

void holdLeft() {
  if (state == CELSIUS_STATE || state == FAHRENHEIT_STATE) {
    last_millis = millis();
    state = MAX_STATE;
  } else if (state == CLF_NO_STATE || state == CLF_YES_STATE) {
    last_millis = millis();
    question_num = 0;
    state = CLF_STATE;
  } else if (state == TEMP_REC_STATE) {
    last_millis = millis();
    temp_f = 0.0;
    temp_c = 0.0;
    state = DEFAULT_STATE;
    powerOFF();
  }
}

void holdClick() {
  if (state == MIN_STATE) {
    bussIT(100);
    sleepSequence();
    state = SLEEP_STATE;
    display.setTextSize(2);
  } else if (state == CELSIUS_STATE || state == FAHRENHEIT_STATE) {
    last_millis = millis();
    selectSequence();
    delay(2000);
    state = MAX_STATE;
  }
}

void holdRecord() {
  if (state == TEMP_REC_STATE) {
    last_millis = millis();
    recordData();
  }
}

void recordData() {
  digitalWrite(LED, HIGH);

  temp_samples.clear();
  temp_f = 0;
  temp_c = 0;

  double temp_object = 0;
  double temp_ambient = 0;

  for (int i = 0; i < SAMPLE_SIZE; i++) {
    temp_samples.add(analogRead(VTH));
    temp_ambient += analogRead(VR);
    delay(30);
  }

  // digitalWrite(BUZZ, LOW);
  temp_object = temp_samples.getAverage();
  temp_ambient /= SAMPLE_SIZE;
  getTemperature(temp_object, temp_ambient);
  digitalWrite(LED, LOW);
}

void getTemperature(double object, double ambient) {
  // Convert ADC reading to voltage
  ambient = ambient / ADC_RES * V_REF;
  object  = object  / ADC_RES * V_REF;
  // Subtract the 2.5V offset that was placed on the pin
  object -= OFFSET;
  // Find the object voltage in mV by removing the gain factor
  object = object / GAIN * MV / CAL_CONST;

  // Find ambient temperature based on voltage
  int ambient_index = 0;
  double ratio = 0;
  bool valid_ambient = false;
  bool valid_temp = false;
  for (int i = 0; i < NUM_AMBIENT - 1; i++) {
    
    if (ambient <= pgm_read_float_near(ambient_chart + i) && ambient >= pgm_read_float_near(ambient_chart + i + 1)) {
      double diff = pgm_read_float_near(ambient_chart + i) - pgm_read_float_near(ambient_chart + i + 1);
      ambient = ambient - pgm_read_float_near(ambient_chart + i + 1);
      ratio = ambient / diff;
      if (ratio >= 0.5) {
        ambient_index = i;
      } else {
        ambient_index = i + 1;
      }
      valid_ambient = true;
    }
  }

  if (valid_ambient) {
    for (int i = 0; i < MAX_TEMP_SIZE - 1; i++) {
      float temp1 = pgm_read_float_near(temp_chart[ambient_index] + i);
      float temp2 = pgm_read_float_near(temp_chart[ambient_index] + i + 1);
      if (object >= temp1 && object <= temp2) {
        if (object - temp1 > temp2 - object) {
          temp_c = (i + 1) * 0.1 + 35;
        } else {
          temp_c = i * 0.1 + 35;
        }
        valid_temp = true;
      }
    }
  }

  if (valid_ambient && valid_temp) { 
    temp_f = temp_c * 1.8 + 32;
  } else {
    temp_c = -1;
    temp_f = -1;
  }
  bussIT(100);
}

void drawIcon() {
  display.drawBitmap(4, 6, menu_bmp, 20, 20, SSD1306_WHITE);
  if (ble_connected) {
    display.drawBitmap(104, 6, ble_on_bmp, 20, 20, SSD1306_WHITE);
  } else {
    display.drawBitmap(104, 6, ble_off_bmp, 20, 20, SSD1306_WHITE);
  }
}

void bussIT(int down) {
  digitalWrite(BUZZ, HIGH);
  delay(down);
  digitalWrite(BUZZ, LOW);
}
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

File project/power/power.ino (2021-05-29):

#include <OneButton.h>
#include <Wire.h>
#include <Adafruit_SSD1306.h>
#include <avr/pgmspace.h>
#include <RunningMedian.h>

#define PWR_IN 6
#define PWR_OUT 7
#define VTH 14
#define LED 10
#define THERMISTOR 15

#define SE 0.02722
#define ADC2V 0.0049
#define GAIN 496.49
#define AMBIENT 70
#define EXP 4

#define SCREEN_WIDTH 128 // OLED display width, in pixels
#define SCREEN_HEIGHT 32 // OLED display height, in pixels

#define OLED_RESET     -1 // Reset pin # (or -1 if sharing Arduino reset pin)
#define SCREEN_ADDRESS 0x3C ///< See datasheet for Address; 0x3D for 128x64, 0x3C for 128x32
Adafruit_SSD1306 display(SCREEN_WIDTH, SCREEN_HEIGHT, &Wire, OLED_RESET);

bool power_on = false;

float temp = 0;

RunningMedian temp_samples = RunningMedian(50);

void setup() {
  // put your setup code here, to run once:
  pinMode(VTH,INPUT);
  pinMode(THERMISTOR, INPUT);
  pinMode(PWR_OUT, OUTPUT);
  pinMode(LED, OUTPUT);

  digitalWrite(PWR_OUT, HIGH);
  
  // SSD1306_SWITCHCAPVCC = generate display voltage from 3.3V internally
  if(!display.begin(SSD1306_SWITCHCAPVCC, SCREEN_ADDRESS)) {
    // Serial.println(F("SSD1306 allocation failed"));
    for(;;); // Don't proceed, loop forever
  }

  // Show initial display buffer contents on the screen --
  // the library initializes this with an Adafruit splash screen.
  display.display();
  delay(1750); // Pause for 2 seconds

  // Clear the buffer
  display.clearDisplay();
  
  // Default Font
  display.setTextSize(1);
  display.setTextColor(SSD1306_WHITE);
  display.cp437(true);

  digitalWrite(LED, LOW);
}

void loop() {

  display.clearDisplay();
  display.setCursor(25, 9);
//  temp = analogRead(VTH)*ADC2V-2.5;
//  temp /= SE;
//  temp += pow(AMBIENT,EXP);
//  temp = pow(temp, 1/EXP);
  digitalWrite(LED, HIGH);
  temp_samples.clear();
  for(int i = 0; i < 50; i++) {
    temp_samples.add(analogRead(VTH));
    delay(30);
  }
//  //digitalWrite(BUZZ, LOW);
  temp = temp_samples.getAverage();
  display.print(analogRead(THERMISTOR));
  display.setCursor(25, 18);
  
  display.print(temp);
  digitalWrite(LED, LOW);
  
  refresh(1000);

}

void refresh(int displayDelay) {
  display.display();
  delay(displayDelay);
  display.clearDisplay();
}

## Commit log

2021-04-27 add schematic and layout
    [contactless-thermometer.brd, contactless-thermometer.sch]
2021-04-27 add switch
2021-04-27 alignment fix
    [contactless-thermometer.brd, contactless-thermometer.sch]
2021-04-27 alignment issue
    [contactless-thermometer.brd]
2021-04-28 PCB progress
    [contactless-thermometer.brd, contactless-thermometer.sch]
2021-04-29 update silkscreen
    [contactless-thermometer.brd, contactless-thermometer.sch]
2021-04-29 Update 3
    [contactless-thermometer.brd]
2021-04-29 fixed silkscreen
2021-04-30 update silkscreen and schematic
    [contactless-thermometer.brd, contactless-thermometer.sch]
2021-04-30 Major Updates
    [contactless-thermometer.brd]
2021-04-30 big bosses big
    [contactless-thermometer.brd]
2021-04-30 big bouses big
    [contactless-thermometer.brd]
2021-04-30 just wonderful
    [contactless-thermometer.brd]
2021-05-06 update schematics
    [contactless-thermometer.brd]
2021-05-19 arduino menu sketch
2021-05-27 too good bro
    [contactless-thermometer.brd, contactless-thermometer.sch]
2021-05-30 Saturday updates yo
    gotta get more lines
    [contactless-thermometer.brd]

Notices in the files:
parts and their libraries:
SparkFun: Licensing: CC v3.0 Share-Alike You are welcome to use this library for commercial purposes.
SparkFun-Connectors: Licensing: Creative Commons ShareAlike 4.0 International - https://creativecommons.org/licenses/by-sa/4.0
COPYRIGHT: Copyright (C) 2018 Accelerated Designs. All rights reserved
